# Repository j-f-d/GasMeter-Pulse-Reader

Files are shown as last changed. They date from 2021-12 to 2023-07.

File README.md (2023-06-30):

# GasMeter Pulse Reader

This project was forked from https://github.com/optoisolated/GasMeter-Pulse-Reader with the intention of providing the correct MQTT topics, such that it will work with the MQTT integration for https://www.home-assistant.io/ with the minimum of fuss.

I use a nodemocuv2 for monitoring at the moment, rather than the hardware created by @MakerMeik and @optoisolated so the pin I use is different (GPIO14 on D5 instead of GPIO9 or GPIO3). If you want to make the hardware, then you'll need to change this.

The mosquitto server is "mosquitto.home" and the device will look for that name using the DNS server provided by the DHCP configuration. The credentials used are stored in your secrets.h file. I add an entry in my DNS server, such that mosquitto.home redirects to the server which is running the mosquitto service.

The homeassistant MQTT integration is configured for the same server and when reloaded should see a new gas_meter device, which provides 2 entities. The gas_consumption entity is suitable for use with the energy dash board. The gas_flow_rate entity I use to determine how much gas is being used at any given moment.

This schematic and PCB layout will allow you to build, read, tally and report on a standard Pulse-Type Gas and Water Meters. Each trigger event consists of 10L of Gas consumed. This device has been confirmed compatible with the following meters:

* Gameco Model 750 Gas Meter (10L/impulse)

This project was forked from MakerMeik's Gasmeter_with_reed project and has been updated to be completely self-contained, self-powered (or direct powered) and has hardware debounce using a Schmitt trigger.

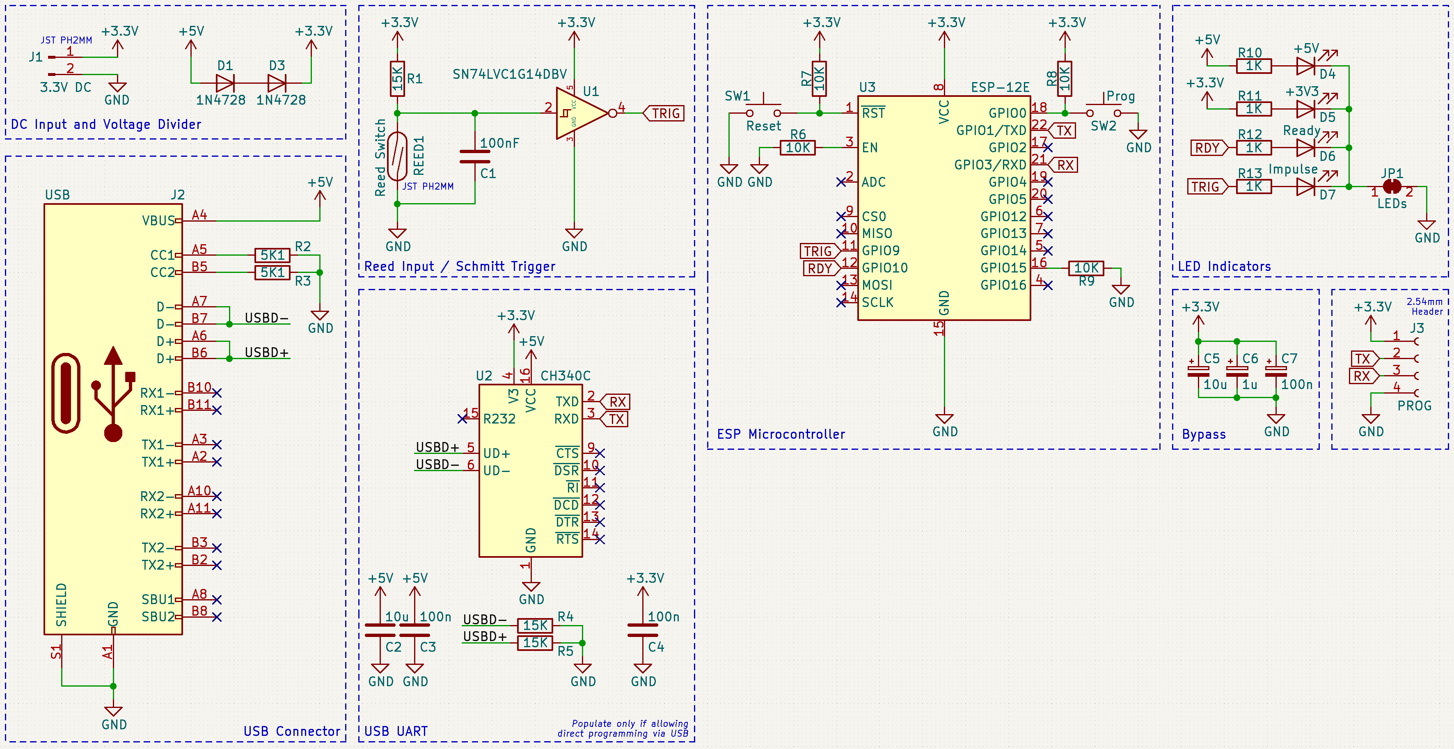
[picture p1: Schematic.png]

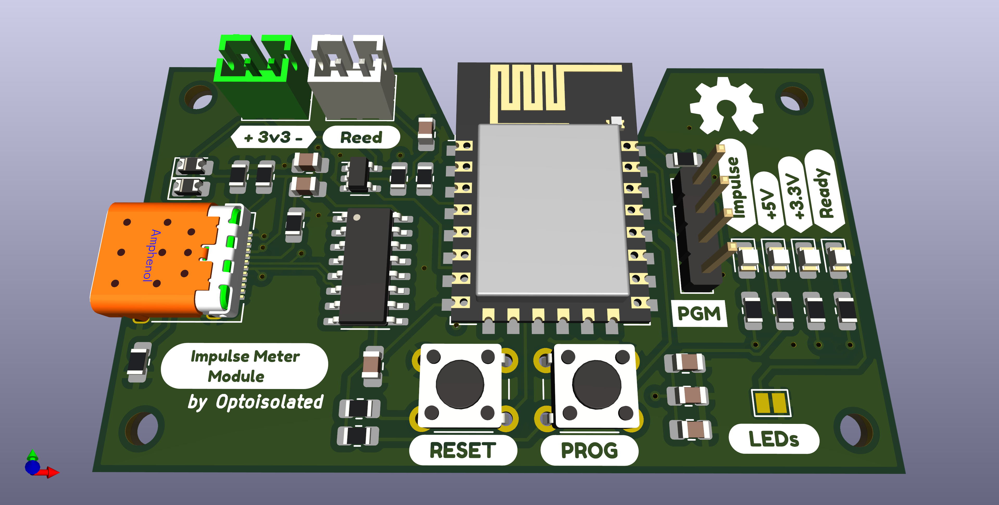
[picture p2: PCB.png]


Here you will find all the files you need to build ESP-01 microcontroller and a reed switch to read your Krom-Schröder gas meter electronically.  



## Links
* MakerMeik's original Project video: https://youtu.be/i9hPf0uNzFE
* Thingiverse - 3D-Model of the case: https://www.thingiverse.com/thing:5338232

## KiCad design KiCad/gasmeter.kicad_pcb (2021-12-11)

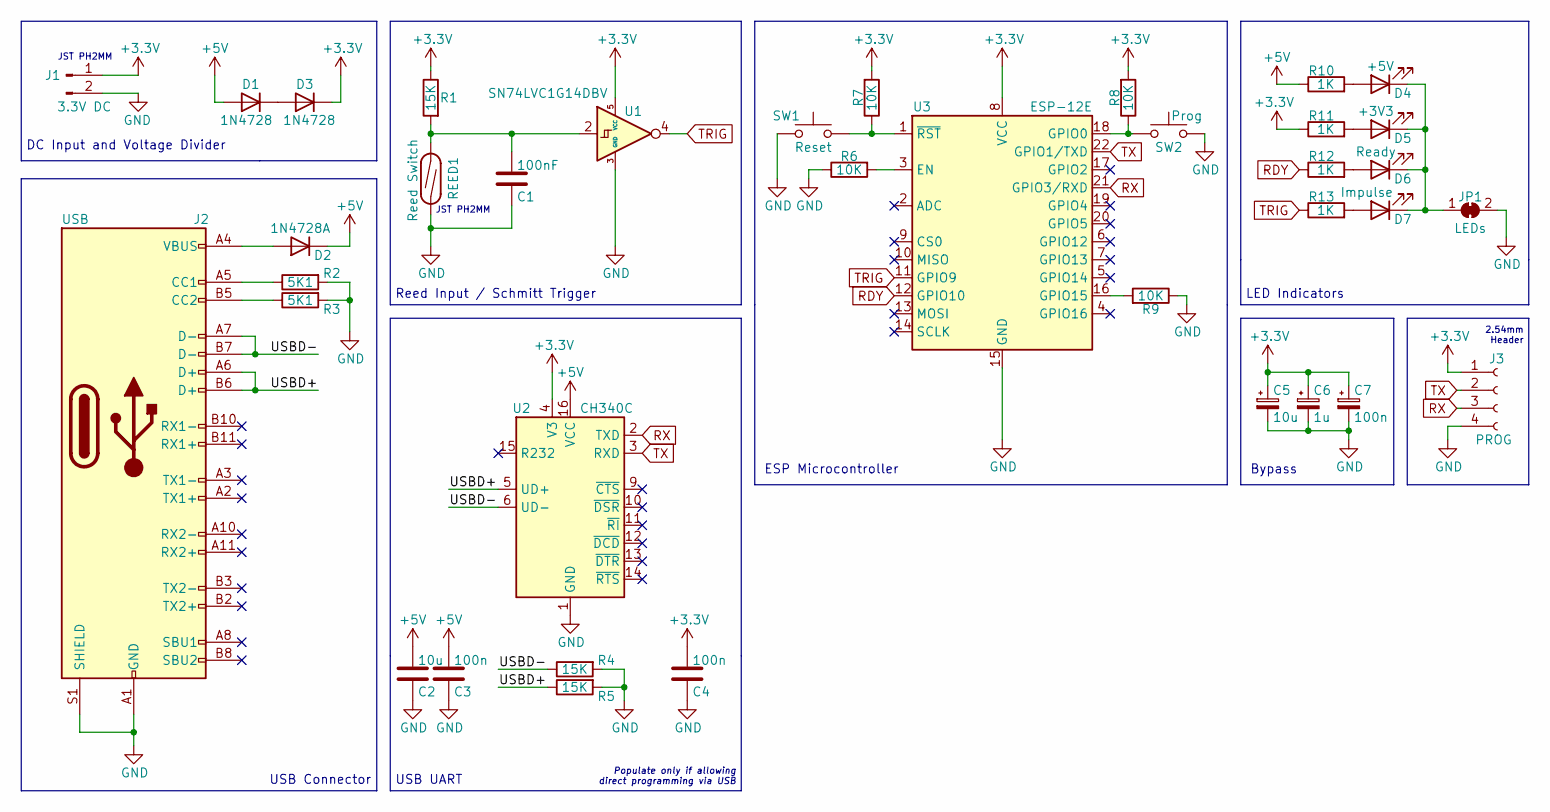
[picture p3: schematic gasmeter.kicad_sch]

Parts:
C1: 100nF; C_0805_2012Metric_Pad1.18x1.45mm_HandSolder
C2, C5: 10u; C_0805_2012Metric_Pad1.18x1.45mm_HandSolder
C3, C4, C7: 100n; C_0805_2012Metric_Pad1.18x1.45mm_HandSolder
C6: 1u; C_0805_2012Metric_Pad1.18x1.45mm_HandSolder
D1, D3: 1N4728; D_0805_2012Metric_Pad1.15x1.40mm_HandSolder
D2: 1N4728A; D_0805_2012Metric_Pad1.15x1.40mm_HandSolder
D4: +5V; LED_0805_2012Metric_Pad1.15x1.40mm_HandSolder
D5: +3V3; LED_0805_2012Metric_Pad1.15x1.40mm_HandSolder
D6: Ready; LED_0805_2012Metric_Pad1.15x1.40mm_HandSolder
D7: Impulse; LED_0805_2012Metric_Pad1.15x1.40mm_HandSolder
J1: 3.3V DC; JST_PH_B2B-PH-K_1x02_P2.00mm_Vertical
J2: USB; USB_C_Receptacle_Amphenol_12401548E4-2A
J3: PROG; PinHeader_1x04_P2.54mm_Vertical
JP1: LEDs; SolderJumper-2_P1.3mm_Bridged_Pad1.0x1.5mm
R1, R4, R5: 15K; R_0805_2012Metric_Pad1.20x1.40mm_HandSolder
R2, R3: 5K1; R_0805_2012Metric_Pad1.20x1.40mm_HandSolder
R6, R7, R8, R9: 10K; R_0805_2012Metric_Pad1.20x1.40mm_HandSolder
R10, R11, R12, R13: 1K; R_0805_2012Metric_Pad1.20x1.40mm_HandSolder
REED1: Reed Switch; JST_PH_B2B-PH-K_1x02_P2.00mm_Vertical
SW1: Reset; SW_SPST_EVQP2
SW2: Prog; SW_SPST_EVQP2
U1: SN74LVC1G14DBV; SOT-23-5
U2: CH340C; SOIC-16_3.9x9.9mm_P1.27mm
U3: ESP-12E

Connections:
+3V3: C4.2, C5.1, C6.1, C7.1, D3.1 (K), J1.1, J3.1, R1.1, R7.2, R8.2, R11.1, U1.5 (VCC), U2.4 (V3), U3.8 (VCC)
/USBD+: J2.A6 (D+), J2.B6 (D+), R5.1, U2.5 (UD+)
/USBD-: J2.A7 (D-), J2.B7 (D-), R4.1, U2.6 (UD-)
GND: C1.1, C2.1, C3.1, C4.1, C5.2, C6.2, C7.2, J1.2, J2.A1 (GND), J2.A12 (GND), J2.B1 (GND), J2.B12 (GND), J2.S1 (SHIELD), J3.4, JP1.2 (B), R2.2, R3.2, R4.2, R5.2, R6.1, R9.1, REED1.1, SW1.1, SW2.2, U1.3 (GND), U2.1 (GND), U3.15 (GND)
unnamed: C1.2, R1.2, REED1.2, U1.2
unnamed: D1.1 (K), D3.2 (A)
unnamed: D4.1 (K), D5.1 (K), D6.1 (K), D7.1 (K), JP1.1 (A)
unnamed: D4.2 (A), R10.2
unnamed: D5.2 (A), R11.2
unnamed: D6.2 (A), R12.2
unnamed: D7.2 (A), R13.2
unnamed: J2.A5 (CC1), R2.1
unnamed: J2.B5 (CC2), R3.1
unnamed: R6.2, U3.3 (EN)
unnamed: R7.1, SW1.2, U3.1 (~RST)
unnamed: R8.1, SW2.1, U3.18 (GPIO0)
unnamed: R9.2, U3.16 (GPIO15)
RDY: R12.1, U3.12 (GPIO10)
RX: J3.3, U2.2 (TXD), U3.21 (GPIO3/RXD)
TRIG: R13.1, U1.4, U3.11 (GPIO9)
TX: J3.2, U2.3 (RXD), U3.22 (GPIO1/TXD)

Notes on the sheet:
LED Indicators
JST PH2MM
USB Connector
Reed Input / Schmitt Trigger
ESP Microcontroller
2.54mm Header
DC Input and Voltage Divider
USB UART
Populate only if allowing direct programming via USB
Bypass

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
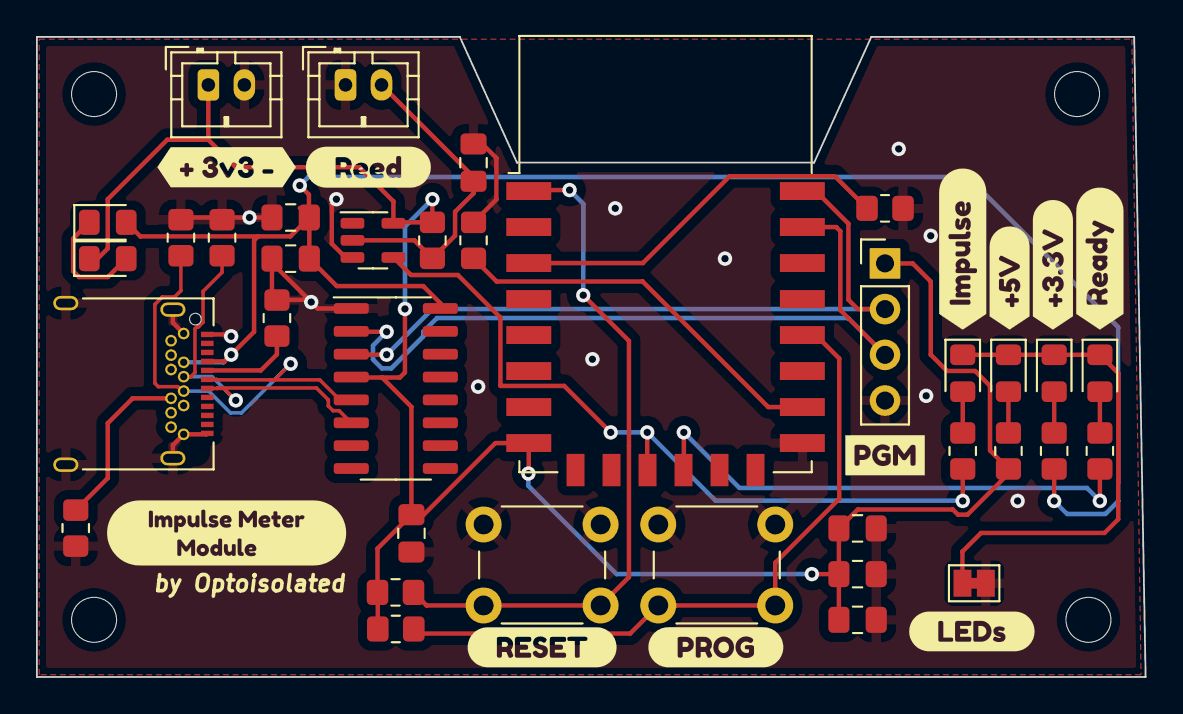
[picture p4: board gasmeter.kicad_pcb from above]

Board: 2 copper layers, 61.6 x 35.6 mm, 47 parts (0 on the bottom side), 22 nets.

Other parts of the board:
kibuzzard-61B4AC1D: G***; kibuzzard-61B4AC1D
kibuzzard-61B4AC13: G***; kibuzzard-61B4AC13
kibuzzard-61B4AC28: G***; kibuzzard-61B4AC28
kibuzzard-61B4AC41: G***; kibuzzard-61B4AC41
kibuzzard-61B4AE0E: G***; kibuzzard-61B4AE0E
kibuzzard-61B4AE05: G***; kibuzzard-61B4AE05
kibuzzard-61B51C34: G***; kibuzzard-61B51C34
kibuzzard-61B51C69: G***; kibuzzard-61B51C69
kibuzzard-61B51CF9: G***; kibuzzard-61B51CF9
kibuzzard-61B51D56: G***; kibuzzard-61B51D56
kibuzzard-61B52BC4: G***; kibuzzard-61B52BC4

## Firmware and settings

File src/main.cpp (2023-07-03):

#include <Arduino.h>
#ifdef ARDUINO_ARCH_ESP8266
#include <ESP8266WiFi.h>
#else
#error "What is the correct header for you platform?"
#endif
#include <PubSubClient.h>
#include <ArduinoJson.h>
#include <Bounce2.h>
#include <secrets.h>

#ifndef DIM
#define DIM(x) (sizeof(x)/sizeof(x[0]))
#endif

#define USE_DHCP
#define SERIAL_LOGGING
// Enabling MQTT_SUBSCRIBE allows the current meter count to be set by changing an MQTT topic,
// but isn't really desirable because it results in big jumps in the readings.
//#define MQTT_SUBSCRIBE

// Enter your passwords in the secrets.h file. You can use the secrets.h.template file for this purpose.
const char* ssid = SECRET_SSID;
const char* password = SECRET_PASS;
#ifndef USE_DHCP
IPAddress ip(192, 168, 188, 103);
IPAddress gateway(192, 168, 188, 34); 
IPAddress subnet(255, 255, 255, 0);
#endif
WiFiClient wifi;
WiFiEventHandler gotIpEventHandler, disconnectedEventHandler;
uint8_t macAddress[WL_MAC_ADDR_LENGTH];
char macAddressStr[3 + (2*WL_MAC_ADDR_LENGTH)];
// This default locally administered MAC address is just used to reserve space in the strings
#define DEFAULT_MAC "0xEE0102010203"

#ifndef USE_DHCP
IPAddress mqtt_server = gateway; // Or wherever.
#else
// Set up a DNS alias on your lan for the machine which runs the mosquitto server.
//IPAddress mqtt_server(192,168,188,181); // Or wherever.
const char* mqtt_server = "mosquitto.lan";
#endif
const char* mqtt_user = SECRET_MQTT_USER;
const char* mqtt_pass = SECRET_MQTT_PASS;
const unsigned int mqtt_port = 1883;
const char clientId[] = "gas_meter";
// https://www.home-assistant.io/integrations/mqtt/
const char sensorPrefix[] = "homeassistant/sensor/";
const char consumption[]  = "consumption";
const char flowRate[]     = "flow_rate";
const char config[]       = "config";
const char state[]        = "state";
String stateTopic;
String consumptionConfigTopic;
String flowRateConfigTopic;
#ifdef MQTT_SUBSCRIBE
// Subscribe to topic used to change the consumption count.
const char status[] = "status";
String statusSubscribeTopic;
static void mqtt_callback(char* topic, byte* payload, unsigned int length);
#endif

static void mqtt_reconnect(void);
static void mqtt_publish_state(double meterVal, double flow_rate);
PubSubClient mqtt_client(mqtt_server, mqtt_port, wifi);
StaticJsonDocument<512> doc;

uint64_t lastReconnectAttempt = 0;
uint64_t lastPulseTime = 0;
bool firstConnect = true;

// The normal units counted are 1/100s of a cubic meter, which is 10L.
unsigned int metercount = 0;
const unsigned int reed_pin = D5; // GPIO14
Bounce reed = Bounce(); // Use a Deboucer to read the reed switch pulses.

static void setup_wifi(){  // Start WiFi-Connection
#ifndef USE_DHCP
  WiFi.config(ip, gateway, subnet); // comment out if your router assigns the IP address automatically via DHCP
#endif
  WiFi.setAutoReconnect(true);

#ifdef SERIAL_LOGGING
  gotIpEventHandler = WiFi.onStationModeGotIP([](const WiFiEventStationModeGotIP& event)
  {
    Serial.print("Station connected, IP: ");
    Serial.println(WiFi.localIP());
  });
#endif
  disconnectedEventHandler = WiFi.onStationModeDisconnected([](const WiFiEventStationModeDisconnected& event)
  {
#ifdef SERIAL_LOGGING
    Serial.println("Station disconnected from WiFi");
#endif
    mqtt_client.disconnect();
    lastReconnectAttempt = 0;
  });
#ifdef SERIAL_LOGGING
  Serial.printf("Connecting to SSID %s\n", ssid);
#endif

  WiFi.begin(ssid, password);
  WiFi.macAddress(macAddress);
  snprintf(macAddressStr, DIM(macAddressStr), "0x%x%x%x%x%x%x",
           macAddress[0], macAddress[1], macAddress[2],
           macAddress[3], macAddress[4], macAddress[5]);
}

void setup() {
#ifdef SERIAL_LOGGING
#ifdef ARDUINO_ARCH_ESP8266
  Serial.begin(74880);
#else
  Serial.begin(115200);
#endif
  Serial.setTimeout(3000);
  while(!Serial) { }
  Serial.println();
  Serial.println();
  Serial.println("Pulse counter starting:");
#endif
  setup_wifi();

  pinMode(LED_BUILTIN_AUX,OUTPUT);
  reed.attach(reed_pin, INPUT_PULLUP);
  reed.interval(5 /*ms*/);

  // Enlarge the MQTT buffer as the config messages can be quite long.
  mqtt_client.setBufferSize(1572);
  // Set up the Topic names that we are using.
  stateTopic = sensorPrefix + String(macAddressStr) + '/' + state;
  consumptionConfigTopic = sensorPrefix + String(macAddressStr) + '/' + consumption + '/' + config;
  flowRateConfigTopic = sensorPrefix + String(macAddressStr) + '/' + flowRate + '/' + config;
#ifdef MQTT_SUBSCRIBE
  statusSubscribeTopic = sensorPrefix + String(macAddressStr) + '/' + status;
  mqtt_client.setCallback(mqtt_callback);
#endif
}

void loop() {
  // Use micros64, to avoid potential glitch at 32bit millis roll over.
  uint64_t now = micros64();

  if (mqtt_client.connected()) {
    mqtt_client.loop();
  } else {
    mqtt_reconnect();
  }

  reed.update();   // read the input pin
  if (reed.changed()) {
    bool reed_state=reed.read();
    digitalWrite(LED_BUILTIN_AUX, reed_state);
    if (reed_state) {
      // Rising edge on reed switch.
      double lpm = 0.0; // Litres per minute.
      metercount++;
#ifdef SERIAL_LOGGING
      Serial.printf("Meter count %d\n", metercount);
#endif

      if (lastPulseTime == 0) {
        // First pulse, so don't have history for useful rate calculation, but use 'now'
        // time for next rising edge.
        lastPulseTime = now;
      } else {
        lpm = (10.0*60000000) / (now - lastPulseTime);
        lastPulseTime = now;
      }
      mqtt_publish_state(metercount/(double)100.0, lpm);
    }
  }
  if (lastPulseTime && (now - lastPulseTime > 60*1000000)) {
    // After 1 min of no pulse assume 0.0 flow rate, by going back to init state.
    lastPulseTime = 0;
    mqtt_publish_state(metercount/(double)100.0, 0.0);
  }
}

void mqtt_create_hass_sensor (const char *name, const char *device_class, const char *state_class,
                              const char *units, const char * value_template) {
  // Ensure the doc is clear first.
  doc.clear();
  // https://www.home-assistant.io/integrations/sensor.mqtt/
  doc["name"] = name;
  doc["unique_id"] = name;
  JsonObject device = doc.createNestedObject("device");
  device["name"] = clientId;
  device["manufacturer"] = ARDUINO_BOARD_ID;
  device["model"] = "PlatformIO Pulse Counter";
  JsonArray ids = device.createNestedArray("identifiers");
  ids.add(macAddressStr);
  if (device_class) { doc["device_class"] = device_class; }
  doc["state_class"] = state_class;
  doc["unit_of_measurement"] = units;
  doc["value_template"] = value_template;
  doc["state_topic"] = stateTopic;
}

static void mqtt_reconnect(void) {
    if (WiFi.status() != WL_CONNECTED) {
      return;
    }
  uint64_t now = micros64();
  if ((lastReconnectAttempt == 0) ||
      (now - lastReconnectAttempt > 5000000)) {
#ifdef SERIAL_LOGGING
    Serial.printf("Connecting to MQTT as %s\n", mqtt_user);
#endif
    lastReconnectAttempt = now;
    if (mqtt_client.connect(clientId,mqtt_user,mqtt_pass)) {
#ifdef MQTT_SUBSCRIBE
      mqtt_client.subscribe(statusSubscribeTopic.c_str());
#endif
      {
        uint8_t payload[512];
        size_t payloadLen;
        
        // https://www.home-assistant.io/integrations/sensor.mqtt/
        // Renitialize the current 'doc' for the "gas_consumption" entity.
        mqtt_create_hass_sensor("gas_consumption", "gas", "total_increasing", "m³", "{{ value_json.reading }}");
        payloadLen = serializeJson(doc, payload, DIM(payload));
        mqtt_client.publish(consumptionConfigTopic.c_str(), payload, payloadLen, true);

        // https://www.home-assistant.io/integrations/sensor.mqtt/
        // Renitialize the current 'doc' for the "gas_flow_rate" entity.
        mqtt_create_hass_sensor("gas_flow_rate", NULL, "measurement", "L/minute", "{{ value_json.flow_rate }}");
        payloadLen = serializeJson(doc, payload, DIM(payload));
        mqtt_client.publish(flowRateConfigTopic.c_str(), payload, payloadLen, true);
      }
      if (firstConnect) {
        // Ensure that home assistant gets the correct behaviour for a total_increasing sensor
        // https://developers.home-assistant.io/docs/core/entity/sensor/#available-state-classes
        mqtt_publish_state(0.0, 0.0);
        firstConnect = false;
      }
    } else {
#ifdef SERIAL_LOGGING
      Serial.printf("Connect failed state: %d\n", mqtt_client.state());
#endif
    }
  }
}

#ifdef MQTT_SUBSCRIBE
static void mqtt_callback(char* topic, byte* payload, unsigned int length) {
#ifdef SERIAL_LOGGING
      Serial.printf("%s=%s\n", topic, payload);
#endif
    if (strcmp(topic,statusSubscribeTopic.c_str()) == 0) {
      String metercount_str;
      for (uint i = 0; i < length; i++) {
        metercount_str += (char)payload[i];
      }
      metercount = metercount_str.toInt();
    }
}
#endif

static void mqtt_publish_state(double meterVal, double flow_rate) {
  if (mqtt_client.connected()) {
    uint8_t payload[128];
    size_t payloadLen;
    doc.clear();
    doc["reading"] = meterVal;
    doc["flow_rate"] = flow_rate;
    payloadLen = serializeJson(doc, payload, DIM(payload));
    mqtt_client.publish(stateTopic.c_str(), payload, payloadLen, false);
  }
}

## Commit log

2021-12-10 Added Schmitt Trigger
    Modified the schematic to include a Schmitt trigger on the input reed switch, and tidied up the design.
    [gasmeter.kicad_sch]
2021-12-10 Cleaned up Schematic Layout
    Layout Cleanup, Added DC Input and protection. Now runs with 5V input.
    [gasmeter.kicad_sch]
2021-12-11 Refactored Design
    * Now runs using an ESP12E
    * LED Indicators added
    * Programming Header
    * Optional USB UART interface onboard
    * USB-C Power/Data (power-only if UART not populated)
    * Diode-based Voltage Divider
    [gasmeter.kicad_sch]
2021-12-11 Prototype PCB Layout
    [gasmeter.kicad_pcb]
